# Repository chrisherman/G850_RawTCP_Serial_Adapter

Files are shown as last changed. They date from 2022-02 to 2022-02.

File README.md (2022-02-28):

**WiFi Raw-TCP Serial Adapter for the Sharp PC-G850** <br>
A Serial to TCP/IP adapter for the Sharp G850V(S) using the 11-pin port and an ESP8266<br>

**Initial Configuration**<br>
config.h contains all relevant default parameters.<br> 
The firmware looks for a config.ini file in LittleFS and will only use the firmware defaults if no config file can be loaded<br>
(note that if you initialize your ESL with SPIFFs, you can upload a config.ini file until your hair falls out - it will always be wiped when the software initializes LittleFS, so make sure you upload any configuration file using LittleFS filesystem)

**AT commands**  (can be set via netcat/telnet or via the G850, e.g. you could save the AT command in text editor and then "save" via the SIO port) to change the WiFI SSID and password or other parameters.<br>
**+++AT+CFG?**<br>
Returns: +++AT+CFG={"rev":1,"sleep":60,"baud":9600,"port":23,"ssid":"GUEST","wifipw":"your_pw_here","host":"G850V.local","otapw":"myOTAPW"}<br> 
The command displays the active configuration<br>

**+++AT+CFG={ "rev":\<n>,<br>
            "sleep":\<n>,<br>
            "baud":\<n>,<br>
            "port":\<n>,<br>
            "ssid":"GUEST",<br>
            "wifipw":"new_pw",<br>
            "host":"G850V.local",<br>
            "otapw":"myOTAPW"} <br>**
Returns: OK

Sets a new configuration. you can set just one parameter or all at once.<br>
**rev**: integer, referencing the version of the configuration. I recommend leaving at 1<br>
**sleep**: seconds until unit goes into deep sleep<br>
**baud**: baudrate for connection with G850 (600...9600)<br>
**port**: TCP/IP port (use 23 for telnet compatibility)<br>
**ssid**: the ssid name of your wifi<br>
**wifipw**: password of your wifi network<br>
**host**: hostname for use when requesting an IP address<br> 
**otapw**: password for protrcting your ota passwords (use espota protocol)<br>

Example:<br>
+++AT+CFG={"ssid":"GUEST","wifipw":"pw"}<br>

**+++AT+SAVE**<br>
Returns: OK
saves current configuration as failsafe.ini to LittleFS Flash file system.<br>
**Pressing the PRG button for longer than 5 sec will load failsafe.ini configuration and reboot.**
This allows you to recover from a messed-up config.ini (e.g. wrong wifi credentials)<br>

**+++AT+SLEEP**<BR>
Puts the adapter immediately into sleep.<br>
Returns: OK<br>

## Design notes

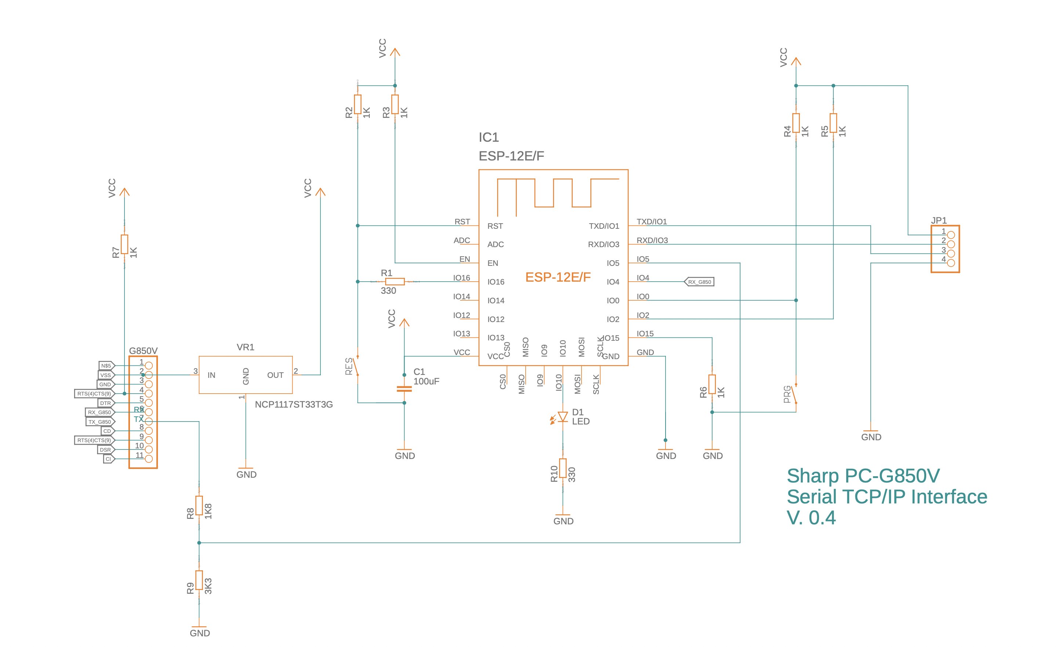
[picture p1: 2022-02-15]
Fusion360/schematics.png

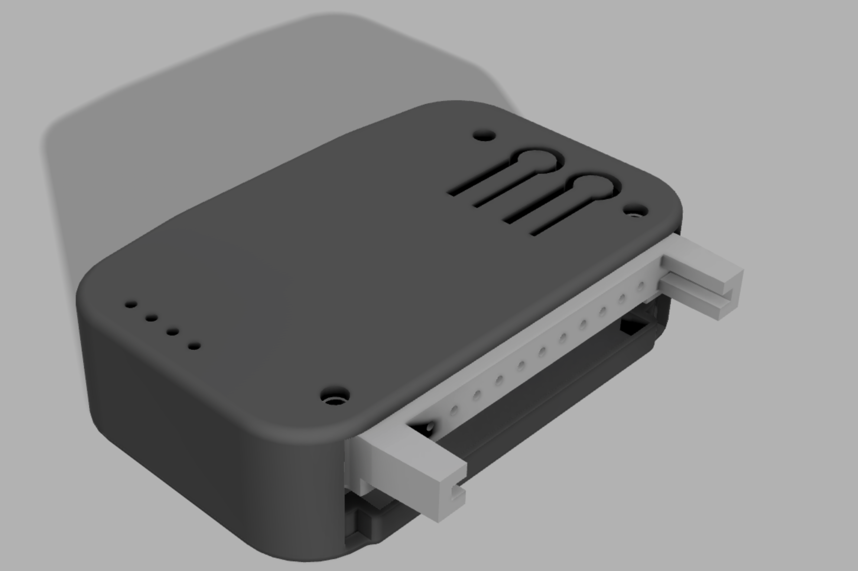
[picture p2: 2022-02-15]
Fusion360/case.png

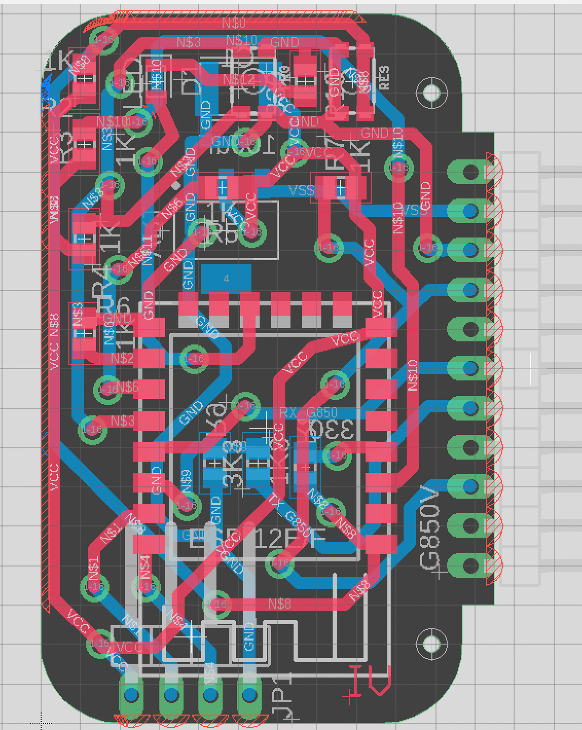
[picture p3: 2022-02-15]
Fusion360/board.png

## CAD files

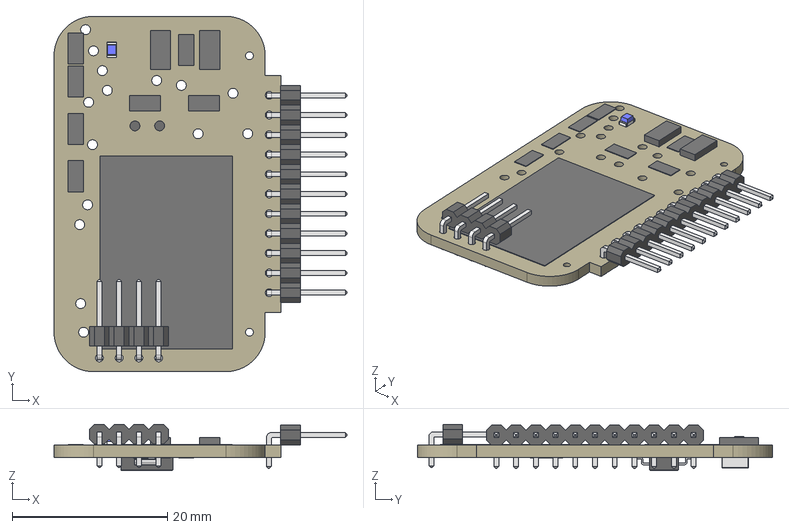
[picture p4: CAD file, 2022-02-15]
Fusion360/Eagle/G850V ESP8266 II v1.step
37.7 x 45.7 x 5.94 mm
Board
CAPC4532X135
1X04/90
1X11/90
SOT230P700X170-4
TACTILE_SWITCH_SMD_4.6X2.8MM x 2
R0805 x 10
ESP-12E

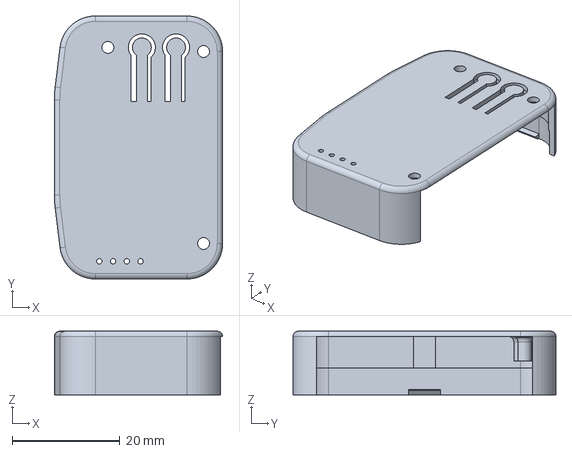
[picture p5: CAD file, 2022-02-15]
Fusion360/STEP/top.step
31.2 x 48.7 x 11.8 mm

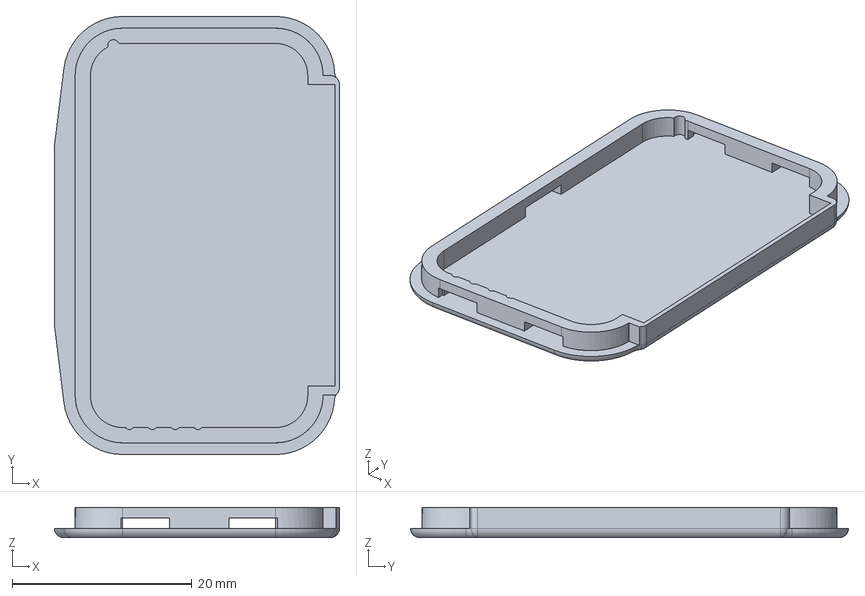
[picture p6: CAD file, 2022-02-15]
Fusion360/STEP/bottom.step
31.7 x 48.7 x 3.35 mm

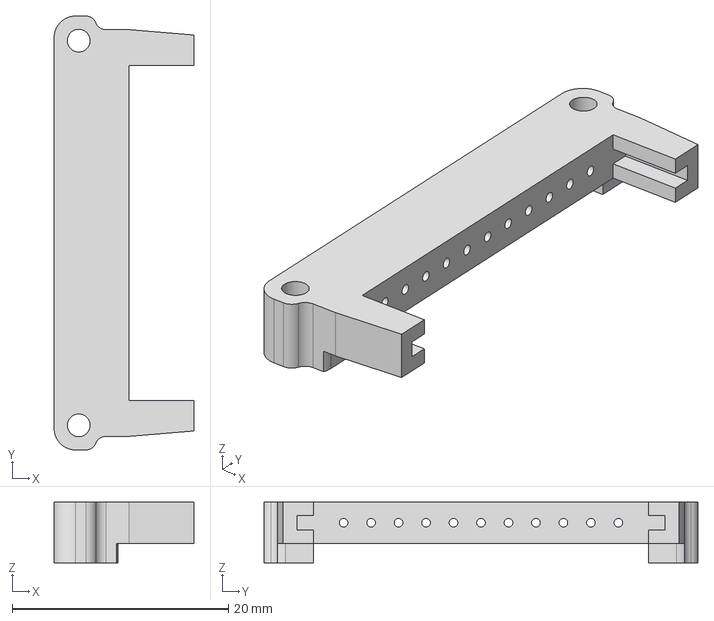
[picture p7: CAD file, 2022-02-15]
Fusion360/STEP/connector.step
12.9 x 40.1 x 5.60 mm

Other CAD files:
Fusion360/STL/bottom.stl
Fusion360/STL/connector.stl
Fusion360/STL/top.stl

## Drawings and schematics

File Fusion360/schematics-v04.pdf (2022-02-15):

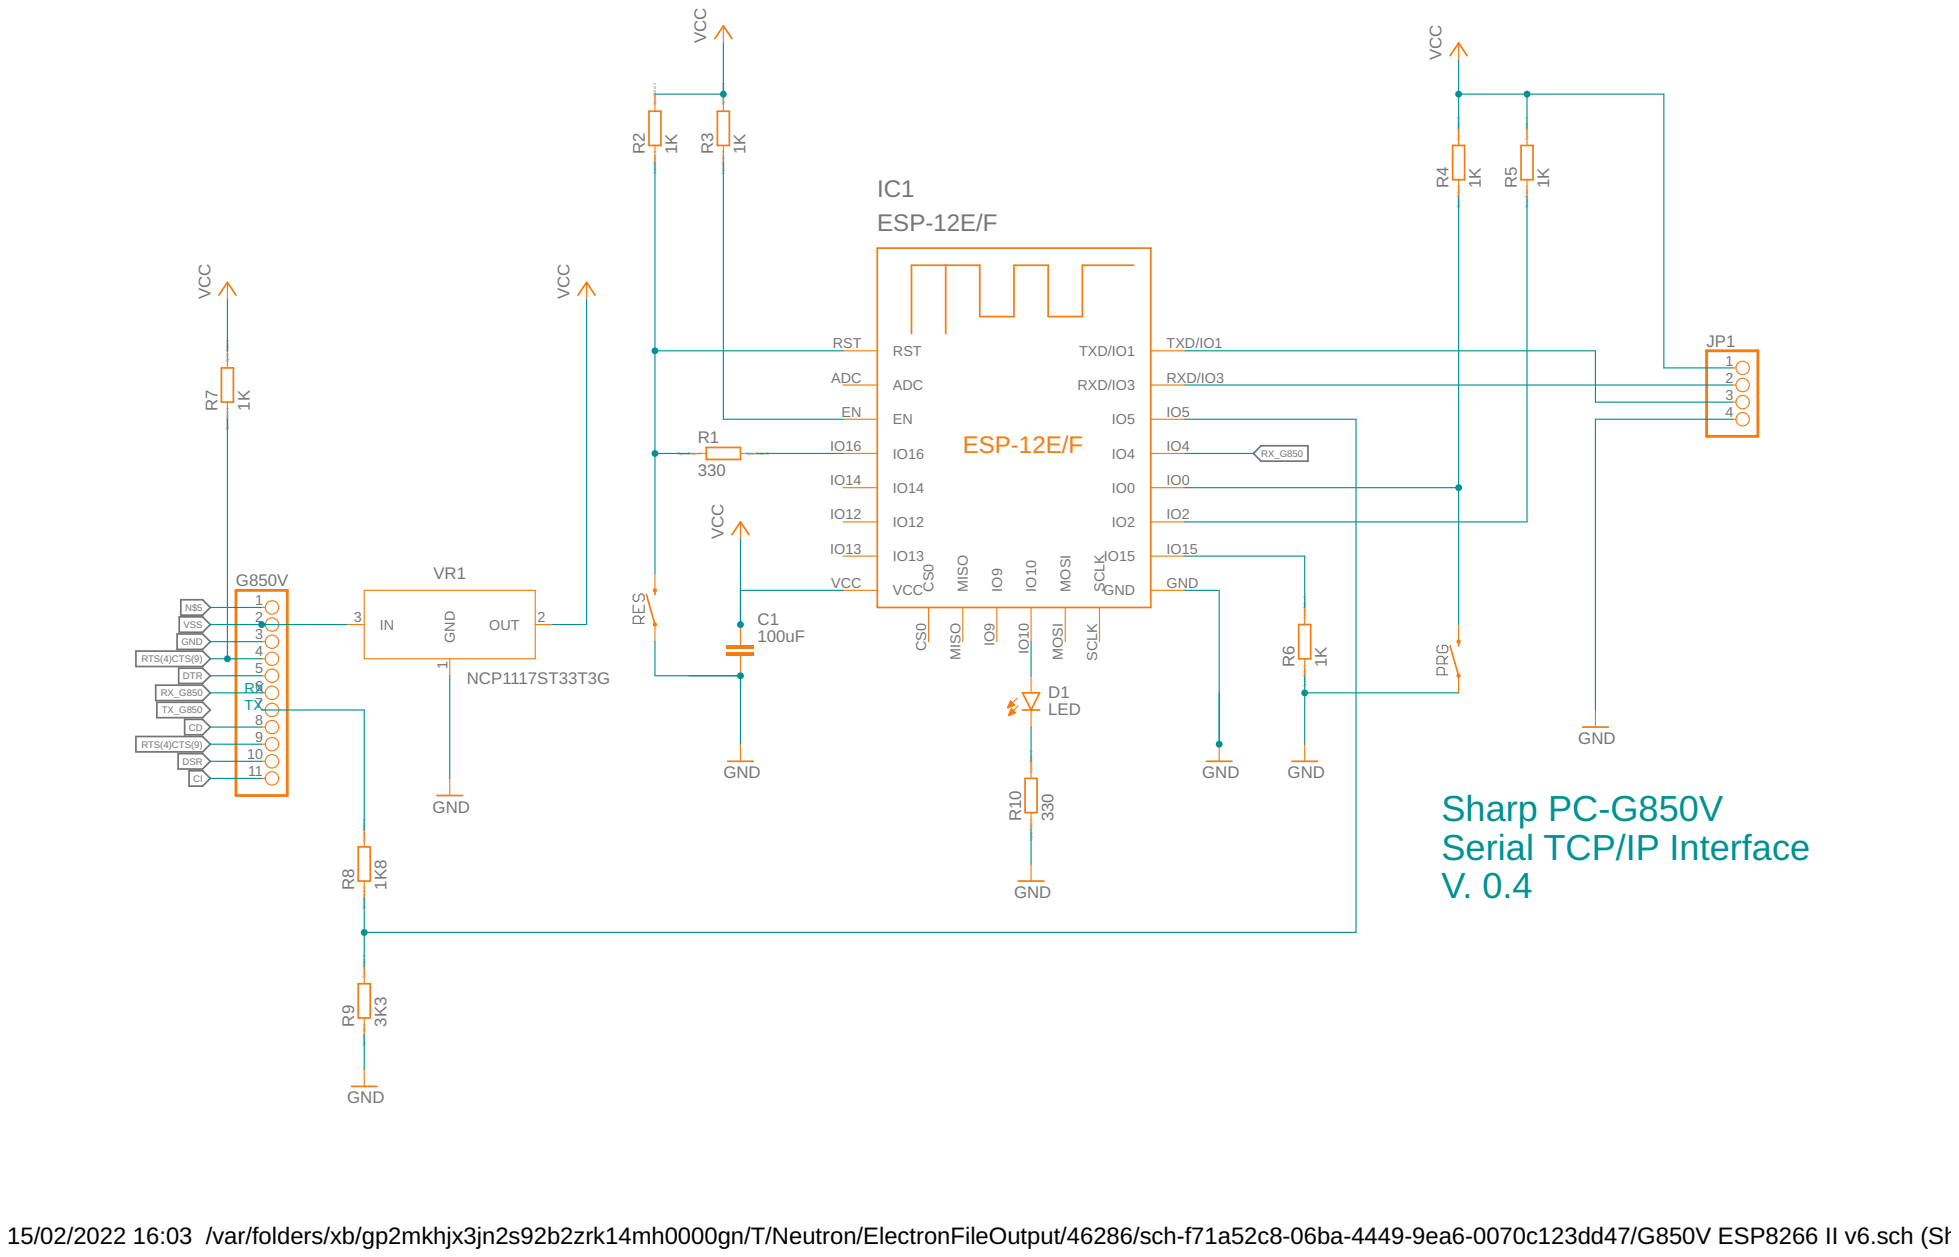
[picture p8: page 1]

RTS(4)CTS(9) RTS(4)CTS(9) RX_G850

SpiceOrder 1 SpiceOrder 2

Serial TCP/IP Interface

15/02/2022 16:03 /var/folders/xb/gp2mkhjx3jn2s92b2zrk14mh0000gn/T/Neutron/ElectronFileOutput/46286/sch-f71a52c8-06ba-4449-9ea6-0070c123dd47/G850V ESP8266 II v6.sch (Sheet: 1/1)

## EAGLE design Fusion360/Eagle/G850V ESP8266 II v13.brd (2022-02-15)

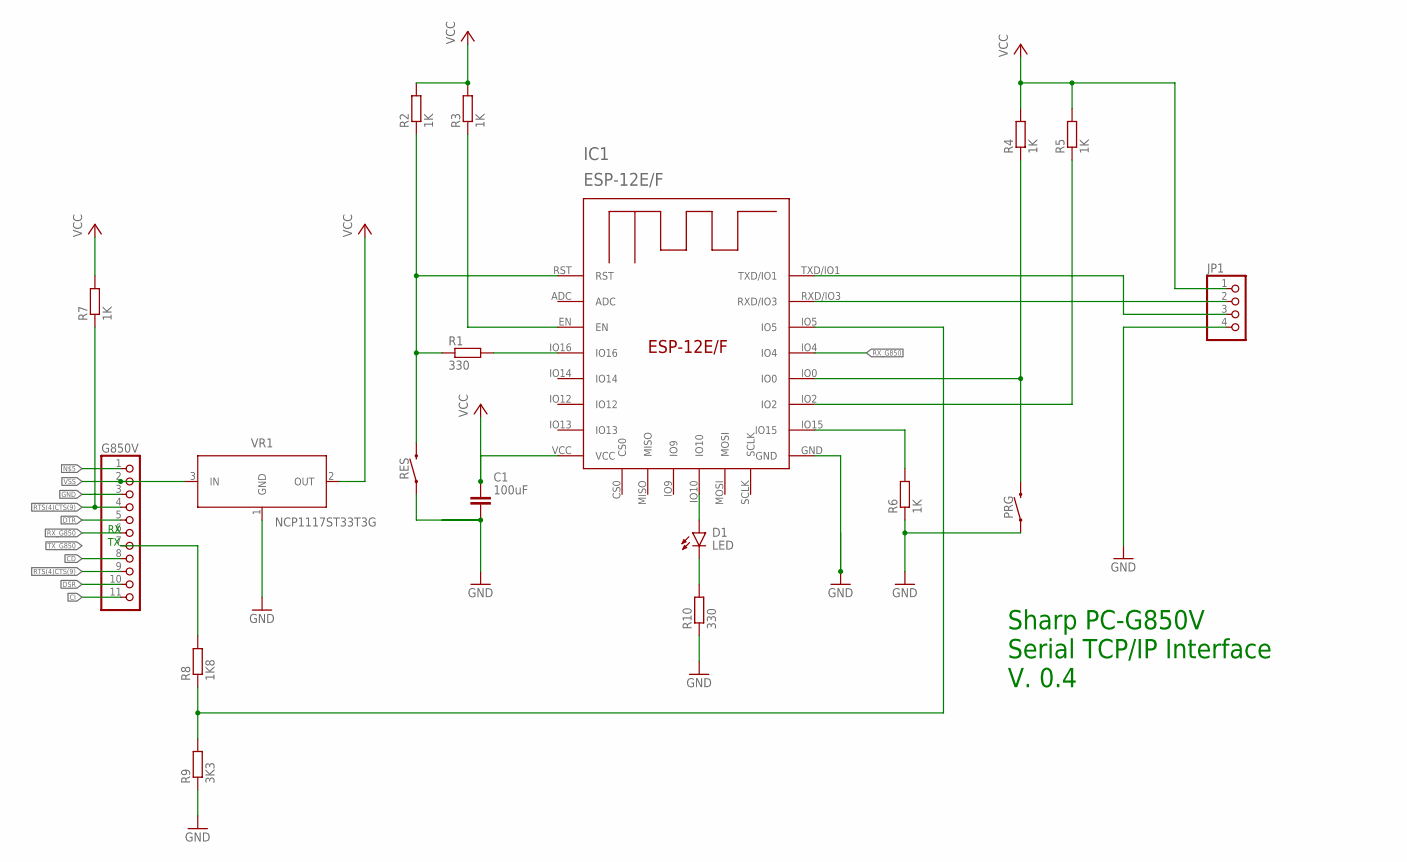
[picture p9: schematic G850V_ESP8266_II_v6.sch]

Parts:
C1: 100uF; CAPC4532X135
D1: LED; LEDC2012X110N_FLAT-B
G850V: PINHD-1X11/90; 1X11/90
IC1: ESP-12E/F; ESP-12E
JP1: PINHD-1X4/90; 1X04/90
PRG: MOMENTARY-SWITCH-SPST-SMD-4.6X2.8MM; TACTILE_SWITCH_SMD_4.6X2.8MM
R1, R10: 330; R0805
R2, R3, R4, R5, R6, R7: 1K; R0805
R8: 1K8; R0805
R9: 3K3; R0805
RES: MOMENTARY-SWITCH-SPST-SMD-4.6X2.8MM; TACTILE_SWITCH_SMD_4.6X2.8MM
VR1: NCP1117ST33T3G; SOT230P700X170-4

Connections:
CD: G850V.8
CI: G850V.11
DSR: G850V.10
DTR: G850V.5
GND: C1.2, G850V.3, IC1.GND, JP1.4, PRG.1, PRG.2 (1), R6.1, R9.1, R10.1, RES.1, RES.2 (1), VR1.1 (GND)
unnamed: IC1.RXD/IO3, JP1.2
unnamed: IC1.IO15, R6.2
unnamed: IC1.IO0, PRG.3 (2), PRG.4 (2), R4.1
unnamed: IC1.TXD/IO1, JP1.3
unnamed: IC1.IO2, R5.1
unnamed: IC1.IO16, R1.2
unnamed: IC1.RST, R1.1, R2.1, RES.3 (2), RES.4 (2)
unnamed: IC1.IO5, R8.1, R9.2
unnamed: IC1.EN, R3.1
unnamed: D1.A, IC1.IO10
unnamed: D1.C, R10.2
RTS(4)CTS(9): G850V.4, G850V.9, R7.1
RX_G850: G850V.6, IC1.IO4
TX_G850: G850V.7, R8.2
VCC: C1.1, IC1.VCC, JP1.1, R2.2, R3.2, R4.2, R5.2, R7.2, VR1.2 (OUT)
VSS: G850V.2, VR1.3 (IN)

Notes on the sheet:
Sharp PC-G850V Serial TCP/IP Interface V. 0.4

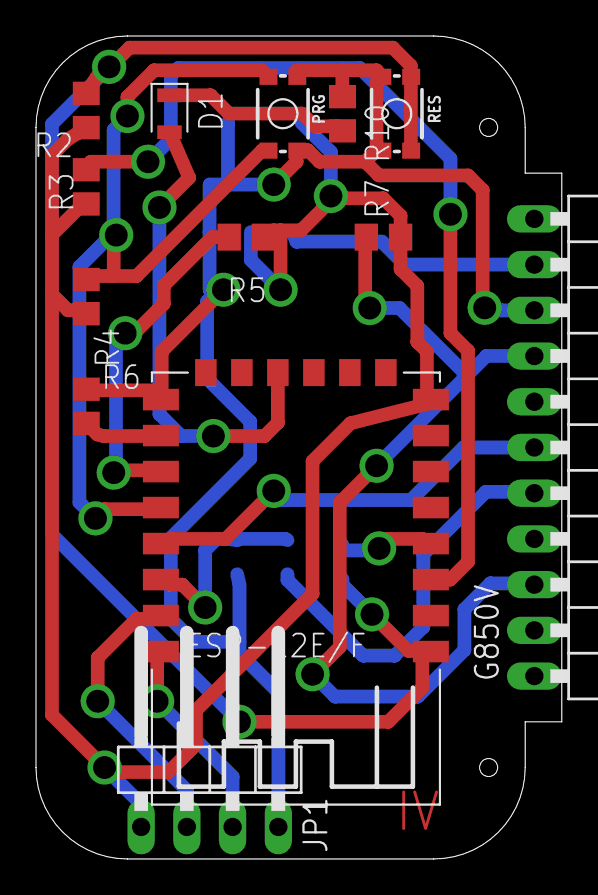
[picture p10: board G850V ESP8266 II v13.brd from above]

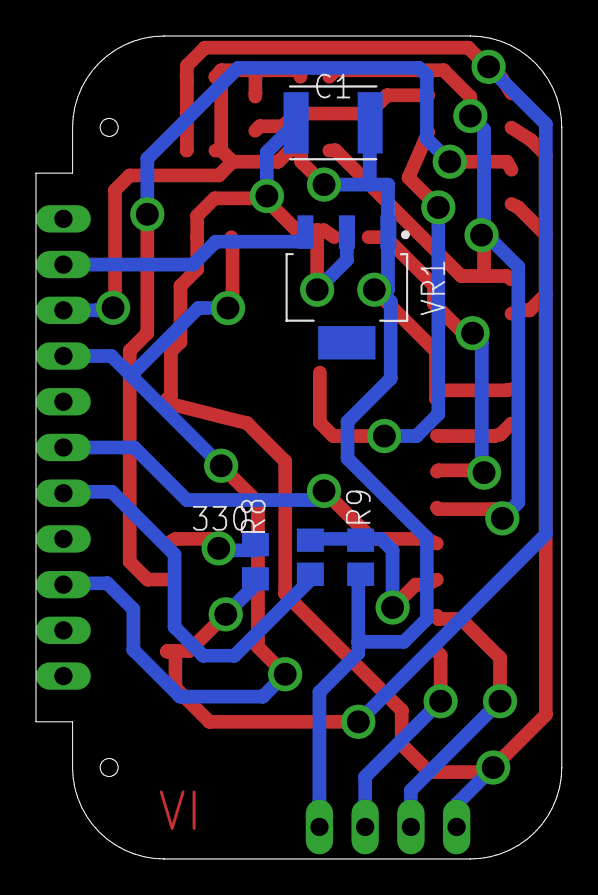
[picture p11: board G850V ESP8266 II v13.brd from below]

Board: 2 copper layers, 29.2 x 45.7 mm, 18 parts (5 on the bottom side), 17 nets.

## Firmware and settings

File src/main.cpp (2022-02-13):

/*****************************************************************
 * Sharp PC-G850V(S) ESP32 Interface
 * By: ChrisHerman
 * Date: December 5th, 2021
 *
 * Receives files from Sharp G850 and sends to PC via USB-Serial (Nano)
 * Requires G850's RTS and CTS lines to be connected witch each other 
 * and pulled-up to +5V. otherwise SHarp will wait forever.
 * 
 *
 * Hardware Hookup:
 * * 
 * Sharp G850 11 pin port            ESP32
 *=========================================
 *  GND (pin 3) __________________ GND
 * 
 * Rx (pin 6)  ___________________ GPIO4 (Tx)
 * 
 * Tx (pin 7)  ___________________ GPIO5 (Rx)
 * 
 * RTS (pin 4) __________
 *                       |
 * CTS (pin 9) __________+
 *                       |
 * +5V         ---[10K]--+
 * 
 *
 * This code is released under the [MIT License](http://opensource.org/licenses/MIT).
 *****************************************************************/



#include <SoftwareSerial.h>
#include <ESP8266WiFi.h>
#include <ESP8266mDNS.h>
#include <ArduinoOTA.h>
#include <LittleFS.h>
#include <Ticker.h>  
#include "config.h"
#include "ATScanner.h"


//below to ensure Strings from platformio.ini are handled as intended by pre-compiler
#define ST(A) #A
#define STR(A) ST(A)

#define RX_PIN 5
#define TX_PIN 4 



//#define LED_PIN 2
#define LED_PIN 10
#define LEDON 0x1
#define LEDOFF 0x0
const int BlinkDelay= 10; // blink period in ms

// second button on the PCB should be PRG-pin
#define PRG_PIN 0

#ifndef SLEEPTIMER_DIV
  #define SLEEPTIMER_DIV 10
#endif



//SoftSerial related objects
#define BUFFER_SIZE 1024    
byte buff[BUFFER_SIZE];
SoftwareSerial SoftSerial(RX_PIN, TX_PIN, true); // RX, TX, inverse_logic = true
void GoTheFuckToSleep();
ATScanner SoftATscanner(SoftSerial, GoTheFuckToSleep);



// global objects
WiFiEventHandler gotIpEventHandler, disconnectedEventHandler;
WiFiServer server(RAW_TCP_PORT);
WiFiClient  client;

void checkFlash(){
#ifdef DEBUG
  uint32_t realSize = ESP.getFlashChipRealSize();
  uint32_t ideSize = ESP.getFlashChipSize();
  FlashMode_t ideMode = ESP.getFlashChipMode();

  Serial.printf("\n");
  Serial.printf("Flash real id:   %08X\n", ESP.getFlashChipId());
  Serial.printf("Flash real size: %u bytes\n", realSize);
  Serial.printf("Flash ide  size: %u bytes\n", ideSize);
  Serial.printf("Flash ide speed: %u Hz\n", ESP.getFlashChipSpeed());
  Serial.printf("Flash ide mode:  %s\n", (ideMode == FM_QIO ? "QIO" : ideMode == FM_QOUT ? "QOUT" : ideMode == FM_DIO ? "DIO" : ideMode == FM_DOUT ? "DOUT" : "UNKNOWN"));

  if (ideSize != realSize) 
    Serial.println("Flash Chip configuration wrong!\n");
  else 
    Serial.println("Flash Chip configuration ok.\n");
#endif

}


void OTASetup(){

  ArduinoOTA.setPassword(GlobalConfig.otapw);
  ArduinoOTA.onStart([]() {
    #ifdef DEBUG
      Serial.println("Start");
    #endif
  });
  ArduinoOTA.onEnd([]() {
    #ifdef DEBUG
      Serial.println("\nEnd");
    #endif
  });
  ArduinoOTA.onProgress([](unsigned int progress, unsigned int total) {
    #ifdef DEBUG
      Serial.printf("Progress: %u%%\r", (progress / (total / 100)));
    #endif
  });

  ArduinoOTA.onError([](ota_error_t error) {
    #ifdef DEBUG
      Serial.printf("Error[%u]: ", error);
      if (error == OTA_AUTH_ERROR) Serial.println("Auth Failed");
      else if (error == OTA_BEGIN_ERROR) Serial.println("Begin Failed");
      else if (error == OTA_CONNECT_ERROR) Serial.println("Connect Failed");
      else if (error == OTA_RECEIVE_ERROR) Serial.println("Receive Failed");
      else if (error == OTA_END_ERROR) Serial.println("End Failed");
    #endif
  });

  ArduinoOTA.begin();
}

void listAllFilesInDir(String dir_path)
{
	Dir dir = LittleFS.openDir(dir_path);
	while(dir.next()) {
		if (dir.isFile()) {
			// print file names
			Serial.print("File: ");
			Serial.println(dir_path + dir.fileName());
		}
		if (dir.isDirectory()) {
			// print directory names
			Serial.print("Dir: ");
			Serial.println(dir_path + dir.fileName() + "/");
			// recursive file listing inside new directory
			listAllFilesInDir(dir_path + dir.fileName() + "/");
		}
	}
}



int GetBaudrate(int i){

  #ifdef DEBUG
    Serial.println( String( "GetBaudrate=") + i);
  #endif

  switch (i){

    case 0: return SOFTBAUDRATE0;
    break;

    case 1: return SOFTBAUDRATE1;
    break;
    
    case 2: return SOFTBAUDRATE2;
    break;
    
    case 3: return SOFTBAUDRATE3;
    break;
    
    case 4: return SOFTBAUDRATE4;
    break;

    default: return SOFTBAUDRATE4;
    break;
  }
}






/////////////////////////////
//what to do with our LED: 
enum blinkstates {Off, Single, Double, Tripple, On} ;
blinkstates blinkstate= Off;

static void blinker(){


  
  #ifdef DEBUG
    //Serial.print("*");
  #endif


  static int cycle= 0;
  cycle++;
  switch (blinkstate){
    case Off: 
      digitalWrite(LED_PIN, LEDOFF); 
      cycle=0;
    break;

    case Single: 
        switch(cycle){
          case 1: digitalWrite(LED_PIN, LEDON); break; 
          case 150: cycle=0; break;
          default: digitalWrite(LED_PIN, LEDOFF); break;
        }
    break;
        
    case Double: 
        switch(cycle){
          case 1: digitalWrite(LED_PIN, LEDON); break; 
          case 20: digitalWrite(LED_PIN, LEDON); break;
          case 170: cycle=0; break;
          default: digitalWrite(LED_PIN, LEDOFF); break;
        }
    break;
    
    case Tripple: 
        switch(cycle){
          case 1: digitalWrite(LED_PIN, LEDON); break; 
          case 21: digitalWrite(LED_PIN, LEDON); break;
          case 41: digitalWrite(LED_PIN, LEDON); break;
          case 190: cycle=0; break;
          default: digitalWrite(LED_PIN, LEDOFF); break;
        }
    break;
    case On: 
        digitalWrite(LED_PIN, LEDON); 
        cycle=0;
    break;

    default: 
      digitalWrite(LED_PIN, LEDOFF);
    break;
  }
}

void SetBlinker(blinkstates bs){
  //set pin as output
  static bool firstcall= true;
  if(firstcall){
      pinMode(LED_PIN, OUTPUT);
      firstcall=false;
  }

  blinkstate= bs;
}

Ticker BlinkTimer(blinker, BlinkDelay, 0, MILLIS);


void GoTheFuckToSleep(){
  digitalWrite(LED_PIN, LEDOFF);
  delay(500);
  while(true){
    ESP.deepSleep(0);   
    delay(100);
  }
}

//////////////////////////////////
// sleep-timout related stuff:
int sleepCountdown=0;
static void SleepCheck(){
  #ifdef DEBUG
    Serial.println("Going to sleep");
  #endif

  sleepCountdown++;

  if(sleepCountdown==(SLEEPTIMER_DIV-1)){
    SetBlinker(Double);
  } else  if(sleepCountdown==SLEEPTIMER_DIV){
    SetBlinker(Tripple);
  } else if(sleepCountdown>SLEEPTIMER_DIV){
    GoTheFuckToSleep();
  } else
    SetBlinker(Single);

}

Ticker SleepTimer(SleepCheck, 30000/SLEEPTIMER_DIV, 0, MILLIS);  //we need to create on the heap otherwise the sleeptimeout is not known


void SleepTimerRestart(){
  sleepCountdown=0;
  SetBlinker(Single);
  SleepTimer.start(); //reset timer
}

// Reset the sleep timer upon button release
void CheckPrgButton(){
  const unsigned long BUTTONPRESSTIME= 5000;        // duration of keypress


  //set PRG pin as input when called first time
  static bool firstcall= true;
  if(firstcall){
    pinMode(PRG_PIN, INPUT);
    firstcall=false;
  }


  static bool wasPressed= false;
  static unsigned long lastpress= 0;


  if(digitalRead(PRG_PIN)==LOW){ //button pressed
    if(wasPressed==false){      // first time that happpened
    wasPressed= true;           // let's remember that
    lastpress=millis();         // and when that happened
    } else {                    // wasPressed flag was already set
      //not really doing anything here...
    }
  } else{ //button not pressed
    if(wasPressed==true){   // but it was pressed just a moment ago
      wasPressed= false;    // let's reset that memory

      if((lastpress+BUTTONPRESSTIME)<millis()){   // button was pressed longer than the timeout time
        #ifdef DEBUG
          Serial.println("PRG button: restoring failsafe config");
        #endif      
        loadFailSafeConfiguration(GlobalConfig);
        saveConfiguration(GlobalConfig);
        #ifdef DEBUG
          Serial.println("restarting with failsafe config");
        #endif  
        delay(1000);
        ESP.reset();
      } else{                                       // was only pressed briefly
        #ifdef DEBUG
          Serial.println("PRG button: timer reset");
        #endif
        SleepTimerRestart();  //payload
      }

    }
  }
}




void setup() {
  #ifdef DEBUG
    Serial.begin(9600);
  #endif
  
  if (LittleFS.begin()){
    #ifdef DEBUG
      Serial.println("File system mounted");
    #endif
  }
  else {
    #ifdef DEBUG
      Serial.println("File system error");
    #endif
  }

  loadConfiguration(GlobalConfig);
  #ifdef DEBUG
    PrintConfig(Serial);
    checkFlash();
    listAllFilesInDir("/");
  #endif

  SleepTimer.interval((GlobalConfig.sleeptimeout*1000)/SLEEPTIMER_DIV);
  SleepTimer.start();
  SetBlinker(On);
  BlinkTimer.start();  

  SoftSerial.begin(GlobalConfig.softbaudrate);

  //WiFi stuff:
  WiFi.begin(GlobalConfig.wifissid, GlobalConfig.wifipassword);
  WiFi.setAutoReconnect(true);
  WiFi.persistent(true);
  gotIpEventHandler = WiFi.onStationModeGotIP([](const WiFiEventStationModeGotIP& event)
  {
    WiFi.setHostname(GlobalConfig.hostname);
    SetBlinker(Single);
    #ifdef DEBUG
      Serial.print("Station connected, IP: ");
      Serial.println(WiFi.localIP());
      Serial.print("Hostname:");
      Serial.println(WiFi.getHostname());
    #endif
  });
  disconnectedEventHandler = WiFi.onStationModeDisconnected([](const WiFiEventStationModeDisconnected& event)
  {
    SetBlinker(On);
    #ifdef DEBUG
      Serial.println("Station disconnected");
    #endif
  });

  delay(200);
  OTASetup();


  server.begin(GlobalConfig.rawport);
  #ifdef DEBUG
    Serial.println("servers started");
  #endif
  SleepTimer.start();
}


void loop() {
  //static unsigned long timer=millis();
  int size = 0;

  client = server.available();              //wait for client connection 

  if (client){

    //clear any bytes received
    while(SoftSerial.available()>0)  {  
      SoftSerial.read();  
    }

    while (client.connected()) {
      ATScanner netscanner(client, GoTheFuckToSleep);
    
      // read data from wifi client and send to serial
      while ((size = client.available())) {
            size = (size >= BUFFER_SIZE ? BUFFER_SIZE : size);
            client.read(buff, size);
            netscanner.scan(buff, size);
            SoftSerial.write(buff, size);
            SoftSerial.flush();
            SleepTimerRestart();
            BlinkTimer.update();
      }
    
      // read data from serial and send to wifi client
      while ((size = SoftSerial.available())) {
            size = (size >= BUFFER_SIZE ? BUFFER_SIZE : size);
            SoftSerial.readBytes(buff, size);
            SoftATscanner.scan(buff, size);
            client.write(buff, size);
            client.flush();
            SleepTimerRestart();
            BlinkTimer.update();
      }
      
      SleepTimer.update();
      BlinkTimer.update();
      ArduinoOTA.handle();
      CheckPrgButton();
    }

    client.stop();    
  }


  //no longer connected
  //keep watching serial port for commands
  while ((size = SoftSerial.available())) {
        size = (size >= BUFFER_SIZE ? BUFFER_SIZE : size);
        SoftSerial.readBytes(buff, size);
        SoftATscanner.scan(buff, size);
        SleepTimerRestart();
        BlinkTimer.update();
        CheckPrgButton();
  }


  SleepTimer.update();
  BlinkTimer.update();
  ArduinoOTA.handle();
  CheckPrgButton();
  delay(5); // w/o this delay., OTA gives you trouble
}

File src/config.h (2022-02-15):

/*****************************************************************************
 * 
 * 
 *  handles all reading and writing and defaulting of configuration items
 * 
 * 
 * 
 * 
 * 
 * 
 * 
 * 
 * 
 * 
 * 
 * 
 * *****************************************************************************/

#ifndef CONFIG_H
#define CONFIG_H

#include <ArduinoJson.h>
#include <LittleFS.h>


#define SERIALBAUDRATE 9600
#define SOFTBAUDRATE0 600
#define SOFTBAUDRATE1 1200
#define SOFTBAUDRATE2 2400
#define SOFTBAUDRATE3 4800
#define SOFTBAUDRATE4 9600



// Our configuration structure.
//
// Never use a JsonDocument to store the configuration!
// A JsonDocument is *not* a permanent storage; it's only a temporary storage
// used during the serialization phase. See:
// https://arduinojson.org/v6/faq/why-must-i-create-a-separate-config-object/
struct Config {
    int revision;
    char wifissid[33];
    char wifipassword[64];
    char hostname[255];  
    char otapw[64];
    int sleeptimeout;
    int softbaudrate;
    int rawport;
};
#define JSONSIZE 512

#define REVISION_TAG "rev"
#ifndef REVISION 
  #define REVISION 1 
#endif

#define RAW_TCP_PORT_TAG "port"
#ifndef RAW_TCP_PORT
  #define RAW_TCP_PORT 23 
#endif

#define WIFISSID_TAG "ssid"
#ifndef WIFISSID
  #define WIFISSID "GUEST"
#endif

#define WIFIPASSWORD_TAG "wifipw"
#ifndef WIFIPASSWORD
  #define WIFIPASSWORD "put_your_wifi_pw_here"
#endif

#define HOSTNAME_TAG "host"
#ifndef HOSTNAME 
  #define HOSTNAME "G850V.local"
#endif

#define OTAPW_TAG "otapw"
#ifndef OTAPW
#define OTAPW "myOTAPW"
#endif

#define SLEEPTIMEOUT_TAG "sleep"
#ifndef SLEEPTIMEOUT
#define SLEEPTIMEOUT 600
#endif

#ifndef MINIMUMSLEEPTIMEOUT
#define MINIMUMSLEEPTIMEOUT 30
#endif

#define SOFTBAUDRATE_TAG "baud"
#ifndef SOFTBAUDRATE
#define SOFTBAUDRATE 9600
#endif

const char* CONFIGFILENAME= "/config.ini";
const char* FAILSAFEFILENAME= "/failsafe.ini";

Config GlobalConfig;                         // <- global configuration object


// Loads the default configuration
void loadDefaultConfiguration(Config &cfg) {
      cfg.revision = REVISION;
      cfg.sleeptimeout = SLEEPTIMEOUT;
      cfg.softbaudrate= SOFTBAUDRATE;
      cfg.rawport= RAW_TCP_PORT;
      strlcpy(cfg.wifissid,  WIFISSID, sizeof(cfg.wifissid));
      strlcpy(cfg.wifipassword, WIFIPASSWORD, sizeof(cfg.wifipassword));
      strlcpy(cfg.hostname, HOSTNAME, sizeof(cfg.hostname));
      strlcpy(cfg.otapw, OTAPW, sizeof(cfg.otapw));
}



void saveConfiguration(const Config &cfg);

// Loads the configuration from a file or string
void readConfigurationFromFile(Config &cfg, const char *filename) {
  #ifdef DEBUG
    Serial.println((String)"Loading Configuration" + filename  );
  #endif

  // Allocate a temporary JsonDocument
  // Don't forget to change the capacity to match your requirements.
  // Use arduinojson.org/v6/assistant to compute the capacity.
  StaticJsonDocument<JSONSIZE> doc;
  DeserializationError error;

  #ifdef DEBUG
    Serial.println(F("deserialize from file"));
  #endif
  File file = LittleFS.open(filename, "r");
  // Deserialize the JSON document
  error = deserializeJson(doc, file);
  // Close the file (Curiously, File's destructor doesn't close the file)
  file.close();

  if (error){
    #ifdef DEBUG
      Serial.println(F("Failed to read file, using default configuration"));
    #endif
    loadDefaultConfiguration(cfg);
    saveConfiguration(cfg);
  }
  else{
    // Copy values from the JsonDocument to the Config
    cfg.revision = doc[REVISION_TAG]|REVISION;
    cfg.sleeptimeout = doc[SLEEPTIMEOUT_TAG]|SLEEPTIMEOUT;
    cfg.sleeptimeout= ((cfg.sleeptimeout<60)?60:cfg.sleeptimeout);
    cfg.softbaudrate= doc[SOFTBAUDRATE_TAG]|SOFTBAUDRATE;
    cfg.rawport= doc[RAW_TCP_PORT_TAG]|RAW_TCP_PORT;
    strlcpy(cfg.wifissid, doc[WIFISSID_TAG]|WIFISSID, sizeof(cfg.wifissid)); 
    strlcpy(cfg.wifipassword, doc[WIFIPASSWORD_TAG]|WIFIPASSWORD, sizeof(cfg.wifipassword));
    strlcpy(cfg.hostname, doc[HOSTNAME_TAG]|HOSTNAME, sizeof(cfg.hostname));         
    strlcpy(cfg.otapw, doc[OTAPW_TAG]|OTAPW, sizeof(cfg.otapw));         
  }
}
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

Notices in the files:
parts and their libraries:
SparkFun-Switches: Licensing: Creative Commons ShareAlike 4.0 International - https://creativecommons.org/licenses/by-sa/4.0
